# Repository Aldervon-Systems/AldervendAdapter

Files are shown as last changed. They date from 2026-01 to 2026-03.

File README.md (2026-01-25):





# AldervendAdapter

Banner

This repo contains all the firmware and hardware for the AldervendAdapter.

If you're looking for the latest docs/builds, see our [Releases Page](https://github.com/Aldervon-Systems/AldervendAdapter/releases).

# Getting Started

First, clone this repo (and optionally checkout a branch)

```shell
git clone https://github.com/Aldervon-Systems/AldervendAdapter.git
cd AldervendAdapter
```

# Init Submodules

Some libraries and resources are included as submodules, run the following
command to initialize them before opening the main sch

(If you get a missing library error, make sure to do this)

```shell
git submodule update --init --recursive
```

## Project Layout

If you want to use this project template for yourself, you can find it [here!](https://github.com/KenwoodFox/Project-Template)

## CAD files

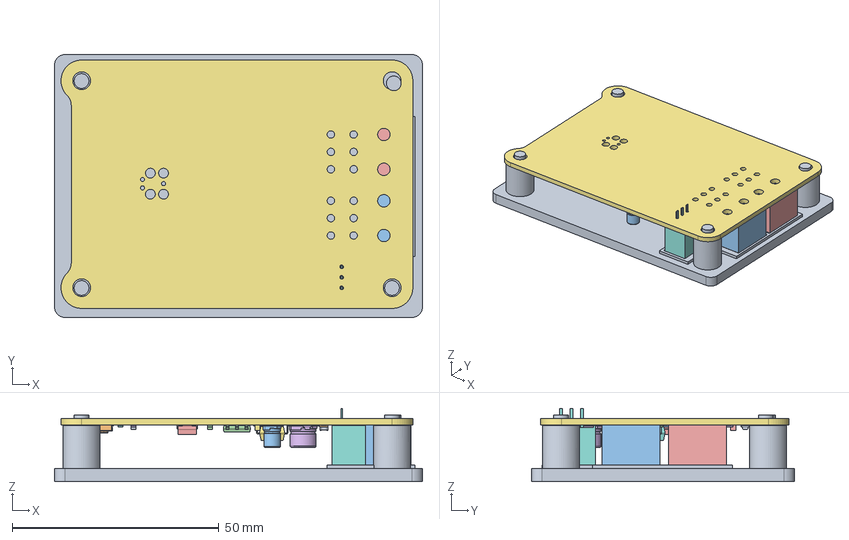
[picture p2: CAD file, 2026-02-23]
CAD/Assembly Frame.FCStd
88.9 x 63.5 x 17.7 mm
SW_Push_1P1T_NO_CK_KMR2
R_0805_2012Metric
R_0805_2012Metric001
C_0805_2012Metric
LED_0805_2012Metric
DIP-4_W7.62mm_SMDSocket
DIP-4_W7.62mm_SMDSocket001
LED_0805_2012Metric001
R_0805_2012Metric002
Molex Jr-Body
LED_0805_2012Metric002
R_0805_2012Metric003
CP_Elec_6.3x5.4
C_0805_2012Metric001
K7805M-1000R3-Body
C_0805_2012Metric002
C_0805_2012Metric003
SW_Push_1P1T_NO_CK_KMR003
SOT-223
D_SMA
R_0805_2012Metric004
R_0805_2012Metric005
R_0805_2012Metric006
C_0805_2012Metric004
R_0805_2012Metric007
C_Elec_4x5.4
R_0805_2012Metric008
Molex Jr-Body001
R_0805_2012Metric009
AldervendAdapter_PCB

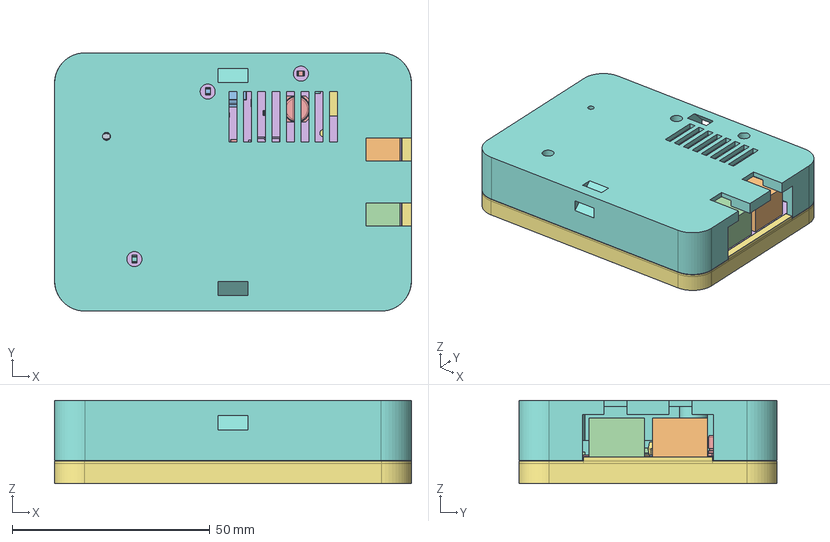
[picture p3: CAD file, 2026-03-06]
CAD/Case.FCStd
90.2 x 65.3 x 21.1 mm
SW_Push_1P1T_NO_CK_KMR2
R_0805_2012Metric
R_0805_2012Metric001
C_0805_2012Metric
LED_0805_2012Metric
SMDIP-4_W9.53mm
SMDIP-4_W9.53mm001
LED_0805_2012Metric001
R_0805_2012Metric002
Molex Jr-Body
LED_0805_2012Metric002
R_0805_2012Metric003
CP_Elec_6.3x5.4
C_0805_2012Metric001
K7805M-1000R3-Body
C_0805_2012Metric002
C_0805_2012Metric003
SW_Push_1P1T_NO_CK_KMR003
SOT-223
D_SMA
R_0805_2012Metric004
R_0805_2012Metric005
R_0805_2012Metric006
C_0805_2012Metric004
R_0805_2012Metric007
C_Elec_4x5.4
R_0805_2012Metric008
Molex Jr-Body001
R_0805_2012Metric009
AldervendAdapter_PCB
Bottom
Top

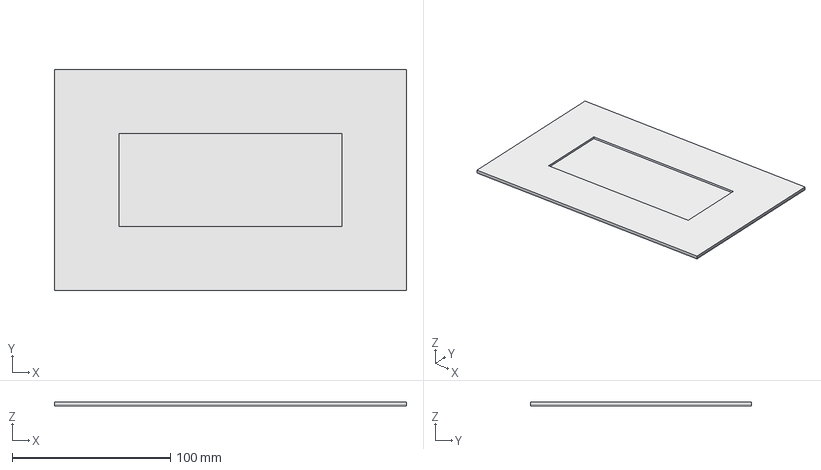
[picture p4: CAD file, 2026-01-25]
Hardware/AldervendAdapter/Stencils/SolderMaskStencil.FCStd
222.2 x 139.7 x 2.60 mm

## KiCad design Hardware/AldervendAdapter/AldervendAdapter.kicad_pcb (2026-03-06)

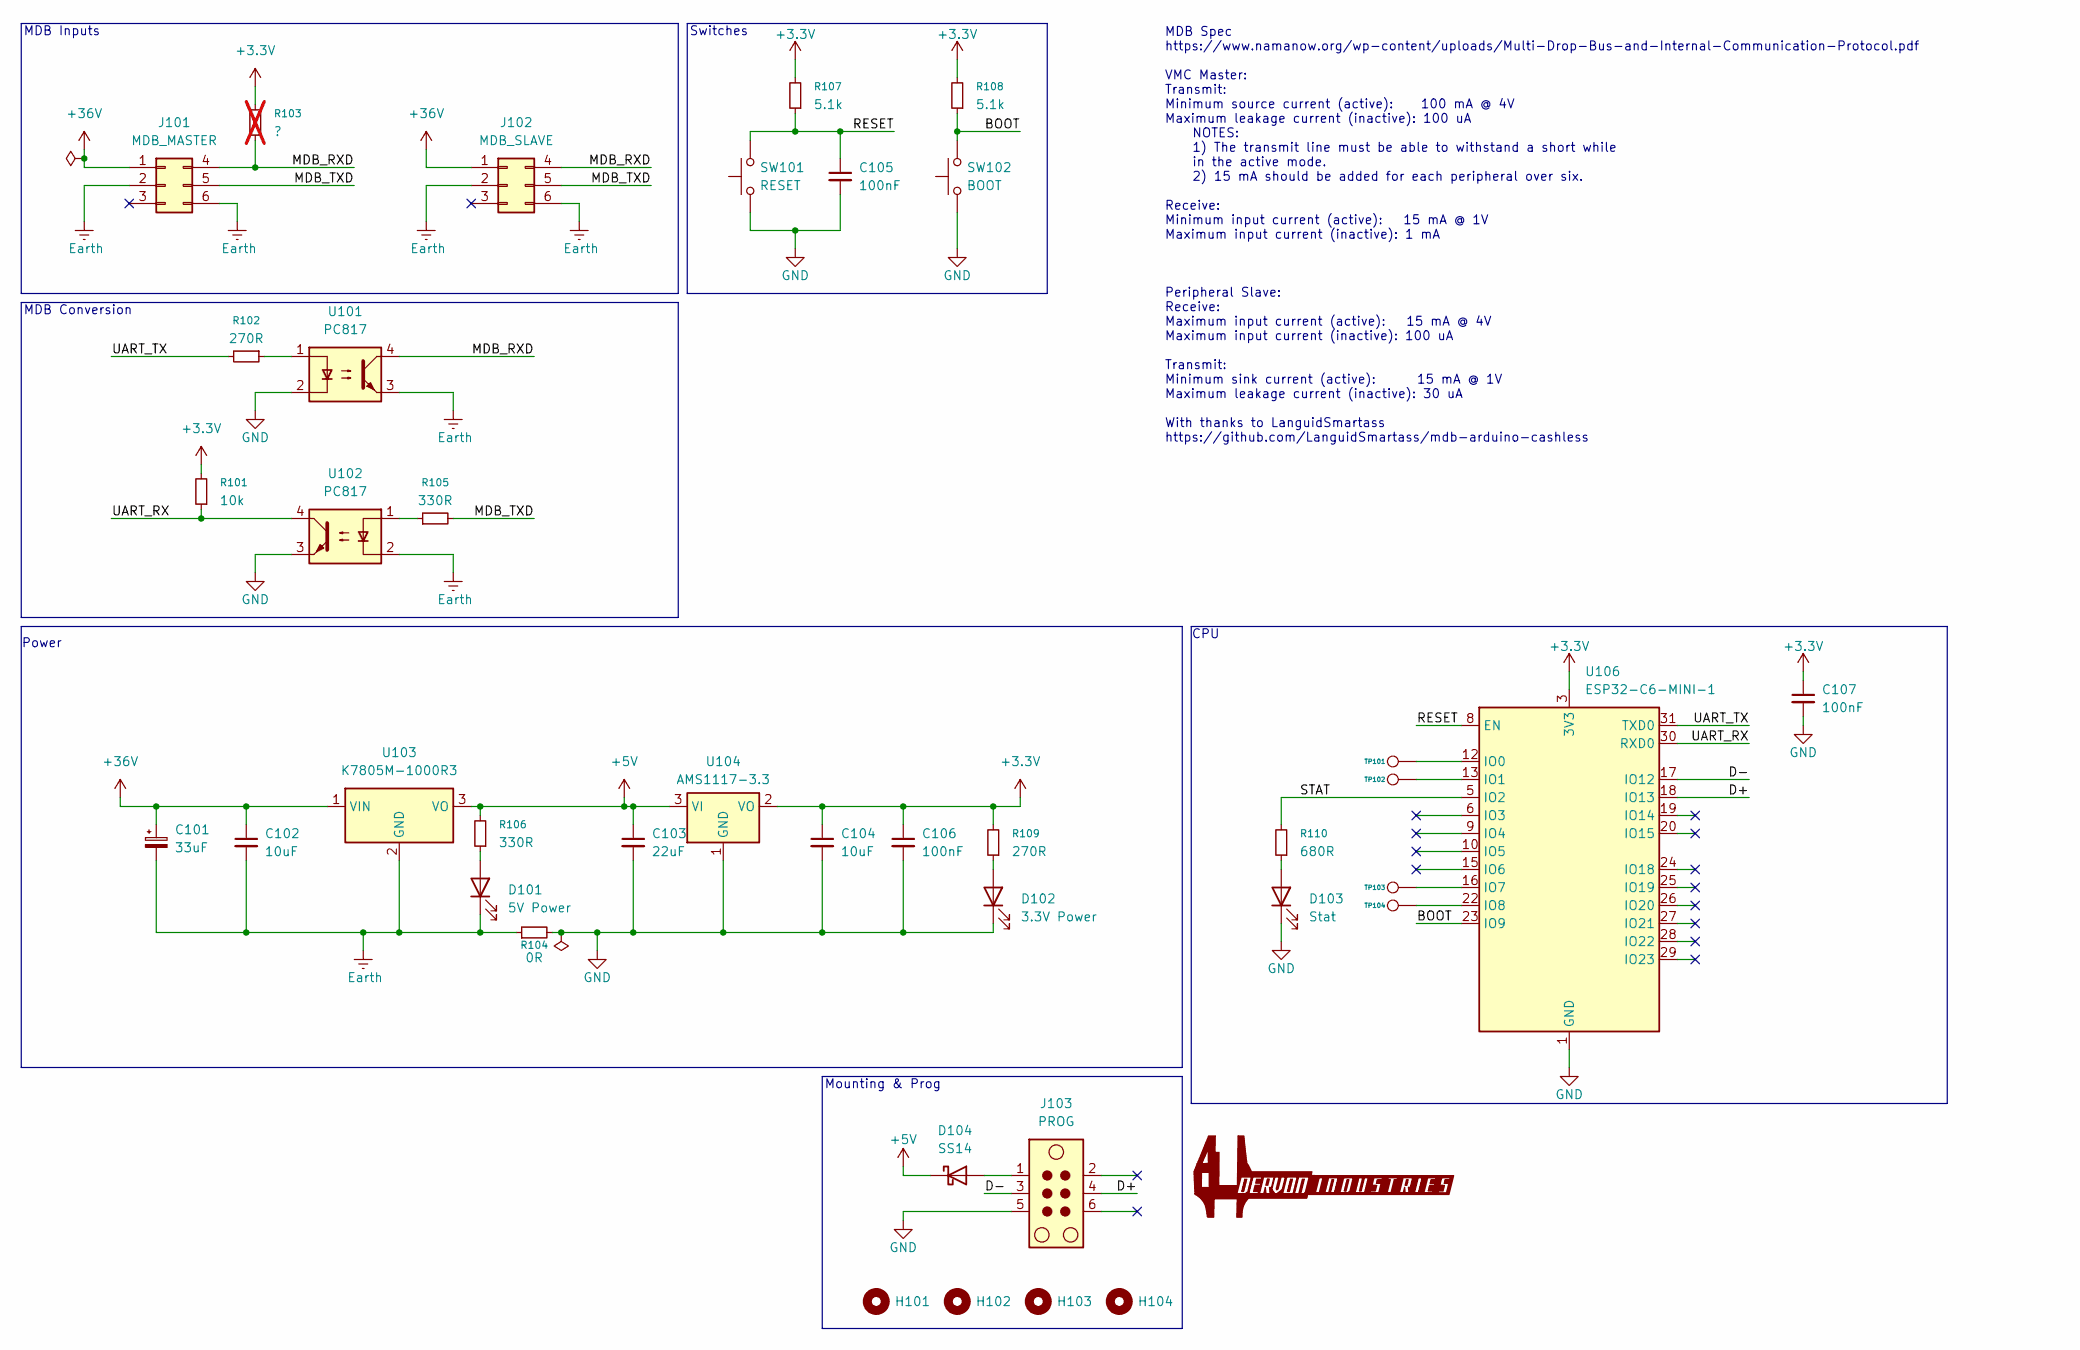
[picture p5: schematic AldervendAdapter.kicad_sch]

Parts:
C101: 33uF; CP_Elec_6.3x5.4; LCSC# C27784
C102, C104: 10uF; C_0805_2012Metric; LCSC# C440198
C103: 22uF; C_Elec_4x5.4; LCSC# C3356
C105, C106, C107: 100nF; C_0805_2012Metric; LCSC# C49678
D101: 5V Power; LED_0805_2012Metric; LCSC# C19171391
D102: 3.3V Power; LED_0805_2012Metric; LCSC# C19171391
D103: Stat; LED_0805_2012Metric; LCSC# C19171391
D104: SS14; D_SMA; LCSC# C83852
H101, H102, H103, H104: MountingHole; MountingHole_4.3mm_M4
J101: MDB_MASTER; Molex_Mini-Fit_Jr_5569-06A2_2x03_P4.20mm_Horizontal
J102: MDB_SLAVE; Molex_Mini-Fit_Jr_5569-06A2_2x03_P4.20mm_Horizontal
J103: PROG; Tag-Connect_TC2030-IDC-FP_2x03_P1.27mm_Vertical
R101: 10k; R_0805_2012Metric; LCSC# C84376
R102, R109: 270R; R_0805_2012Metric; LCSC# C17590
R103: ?; R_0805_2012Metric; not fitted
R104: 0R; R_0805_2012Metric; LCSC# C17477
R105, R106: 330R; R_0805_2012Metric; LCSC# C17630
R107, R108: 5.1k; R_0805_2012Metric; LCSC# C27834
R110: 680R; R_0805_2012Metric; LCSC# C114549
SW101: RESET; SW_Push_1P1T_NO_CK_KMR2; LCSC# C221676
SW102: BOOT; SW_Push_1P1T_NO_CK_KMR2; LCSC# C221676
TP101, TP102, TP103, TP104: TestPoint; TestPoint_Pad_2.0x2.0mm
U101, U102: PC817; SMDIP-4_W9.53mm; LCSC# C66405
U103: K7805M-1000R3; LCSC# C5369649
U104: AMS1117-3.3; SOT-223-3_TabPin2; LCSC# C6186
U105: (no value)
U106: ESP32-C6-MINI-1; LCSC# C5736265

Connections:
+3.3V: C104.1, C106.1, C107.1, R101.2, R103.1, R107.2, R108.2, R109.2, U104.2 (VO), U106.3 (3V3)
+5V: C103.1, D104.1 (K), R106.2, U103.3 (VO), U104.3 (VI)
+36V: C101.1, C102.1, J101.1, J102.1, U103.1 (VIN)
/BOOT: R108.1, SW102.2, U106.23 (IO9)
/D+: J103.4, U106.18 (IO13)
/D-: J103.3, U106.17 (IO12)
/MDB_RXD: J101.4, J102.4, R103.2, U101.4
/MDB_TXD: J101.5, J102.5, R105.2
/RESET: C105.1, R107.1, SW101.2, U106.8 (EN)
/STAT: R110.2, U106.5 (IO2)
/UART_RX: R101.1, U102.4, U106.30 (RXD0)
/UART_TX: R102.2, U106.31 (TXD0)
Earth: C101.2, C102.2, D101.1 (K), J101.2, J101.6, J102.2, J102.6, R104.1, U101.3, U102.2, U103.2 (GND)
GND: C103.2, C104.2, C105.2, C106.2, C107.2, D102.1 (K), D103.1 (K), J103.5, R104.2, SW101.1, SW102.1, U101.2, U102.3, U104.1 (GND), U106.1 (GND), U106.2 (GND), U106.11 (GND), U106.14 (GND), U106.36 (GND), U106.37 (GND), U106.38 (GND), U106.39 (GND), U106.40 (GND), U106.41 (GND), U106.42 (GND), U106.43 (GND), U106.44 (GND), U106.45 (GND), U106.46 (GND), U106.47 (GND), U106.48 (GND), U106.49 (GND), U106.50 (GND), U106.51 (GND), U106.52 (GND), U106.53 (GND)
unnamed: D101.2 (A), R106.1
unnamed: D102.2 (A), R109.1
unnamed: D103.2 (A), R110.1
unnamed: D104.2 (A), J103.1
unnamed: R102.1, U101.1
unnamed: R105.1, U102.1
unnamed: TP101.1, U106.12 (IO0)
unnamed: TP102.1, U106.13 (IO1)
unnamed: TP103.1, U106.16 (IO7)
unnamed: TP104.1, U106.22 (IO8)

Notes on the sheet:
CPU
Mounting & Prog
Switches
MDB Spec https://www.namanow.org/wp-content/uploads/Multi-Drop-Bus-and-Internal-Communication-Protocol.pdf VMC Master: Transmit: Minimum source current (active): 100 mA @ 4V Maximum leakage current (inactive): 100 uA NOTES: 1) The transmit line must be able to withstand a short while in the active 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
MDB Conversion
Power
MDB Inputs

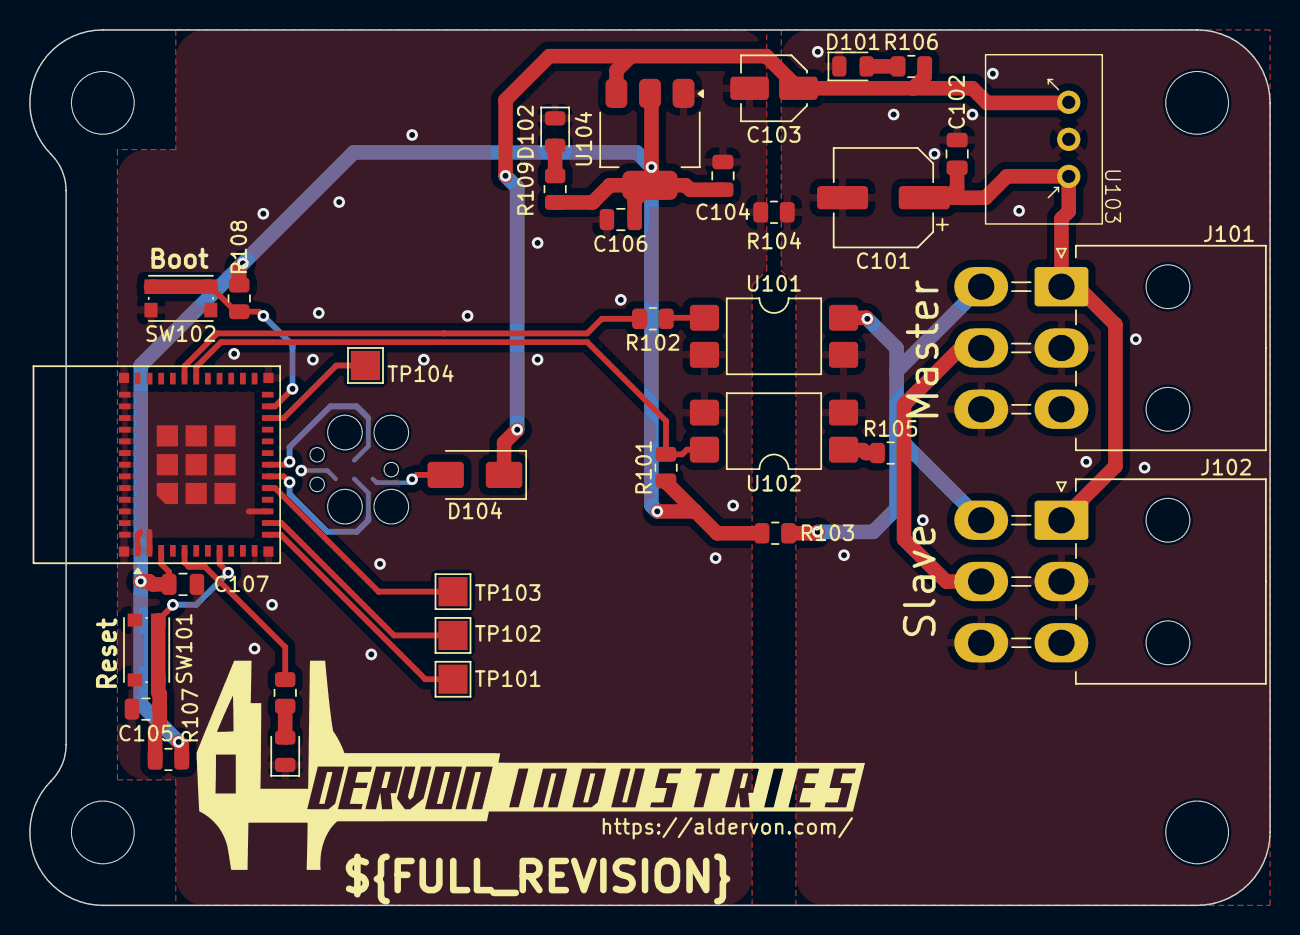
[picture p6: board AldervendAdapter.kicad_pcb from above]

Board: 2 copper layers, 85.0 x 60.0 mm, 39 parts (1 on the bottom side), 24 nets.

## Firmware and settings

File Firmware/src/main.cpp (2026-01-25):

/**
 * @file main.cpp
 * @author Joe
 * @brief Source code for AldervendAdapter
 */

// Libs
#include <Arduino.h>

// Headers
#include "boardPins.h"

void setup()
{
    // Setup serial
    delay(200);
    Serial.begin(115200);
    Serial.println(REVISION);

    // Pins
    pinMode(STAT_LED, OUTPUT);
}

void loop()
{
    // Flash LED
    digitalWrite(STAT_LED, HIGH);
    delay(1000);
    digitalWrite(STAT_LED, LOW);
    delay(1000);
}

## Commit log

2026-01-25 Import from https://github.com/KenwoodFox/Project-Template
    [AldervendAdapter.kicad_pcb, AldervendAdapter.kicad_sch, Cube.FCStd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]
2026-01-26 Bump MVD
    [AldervendAdapter.kicad_pcb, AldervendAdapter.kicad_sch]
2026-01-26 Add aldervon logo
    [AldervendAdapter.kicad_pcb]
2026-01-27 Add 3d
    [AldervendAdapter.kicad_pcb]
2026-01-28 Add some sch work
    [AldervendAdapter.kicad_sch]
2026-02-09 Enough free work for today
    [AldervendAdapter.kicad_pcb, AldervendAdapter.kicad_sch]
2026-02-12 Make aldervon logo
    [AldervendAdapter.kicad_sch]
2026-02-21 Settle in on a vrm and other optos
    [AldervendAdapter.kicad_sch]
2026-02-21 Finish schematic
    [AldervendAdapter.kicad_pcb, AldervendAdapter.kicad_sch]
2026-02-21 Add all but finishing touches
    [AldervendAdapter.kicad_pcb, AldervendAdapter.kicad_sch]
2026-02-21 Find some replacement parts for standard assembly
    [AldervendAdapter.kicad_pcb, AldervendAdapter.kicad_sch]
2026-02-22 Add final
    [AldervendAdapter.kicad_pcb]
2026-02-22 Assign LCSC for THT parts
    [AldervendAdapter.kicad_sch]
2026-02-22 Last style
    [AldervendAdapter.kicad_pcb, AldervendAdapter.kicad_sch]
2026-02-23 Add stencil for PCB tht assembly
    [AldervendAdapter.kicad_pcb, Assembly Frame.FCStd, Cube.FCStd]
2026-02-23 CLean sketch, finish fab (3d print)
    [AldervendAdapter.kicad_sch]
2026-02-23 Fix manufacturing width for iso
    [AldervendAdapter.kicad_pcb, AldervendAdapter.kicad_sch]
2026-03-06 Add inital case
    [Case.FCStd]
2026-03-06 Fix component direction
    [AldervendAdapter.kicad_pcb]
2026-03-06 Finalize top case
    [Case.FCStd]
2026-03-06 Increase depth on bottom of case
    [Case.FCStd]
2026-03-06 Remove prototype branding
    [AldervendAdapter.kicad_pcb]
